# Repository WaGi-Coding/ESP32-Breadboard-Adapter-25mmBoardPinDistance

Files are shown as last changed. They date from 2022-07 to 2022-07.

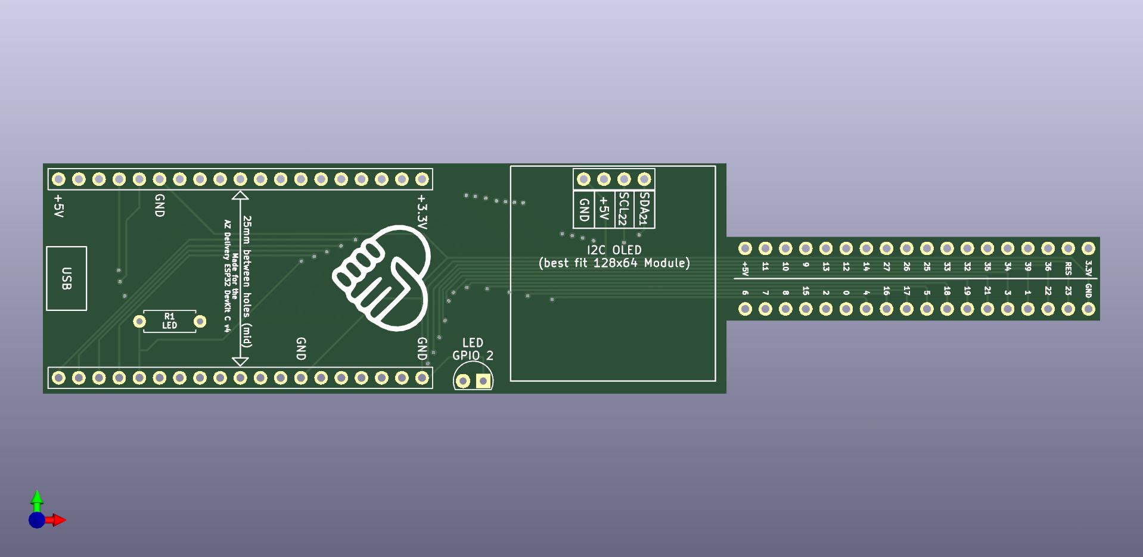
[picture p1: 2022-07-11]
ESP32_DevKit_C_v4-AZDelivery_Breadboard_Adapter.jpg

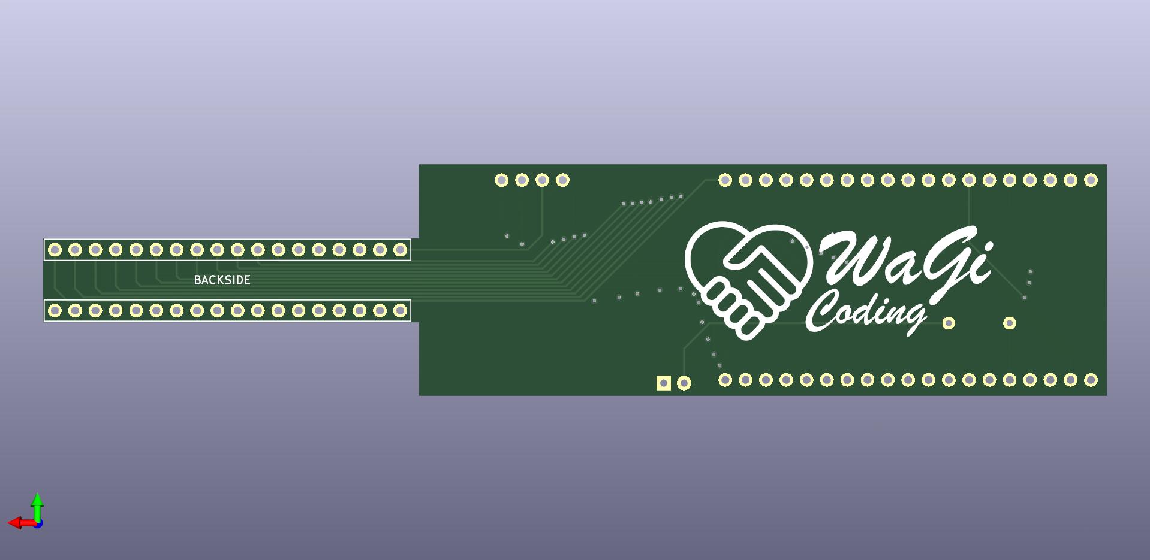
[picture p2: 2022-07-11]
ESP32_DevKit_C_v4-AZDelivery_Breadboard_AdapterBACK.jpg

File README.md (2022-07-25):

# ESP32-Breadboard-Adapter 25mm Board Pin Distance

Breadboard Adapter PCB to better fit an ESP32 DevKit onto your Breadboard. Has a Slot for a LED on GPIO2 and an OLED Screen (128x64).
The Pin Sequence is the same as from the ESP itself, just 2 Ground Pins got removed to save space.

It's designed for the "AZ-Delivery ESP32 DevKit C v4". If you have another Board, check the Pin mid distance, it should be 25mm, also check the Pinout of the mentioned Board.






You can DIRECTLY [ORDER FROM AISLER.NET HERE](https://aisler.net/p/QFYZRXHC) for very cheap. Here is also a 10€ Coupon Code (works atm [Jul. 10th 2022]): uCnet
You can also upload the files to some other PCB Manufacturer for sure.

### You need:
 - 2x 18Pin Male Header
 - 2x 19Pin Female Header (Hard to find, i cut 40 Pin Headers because they are cheap and easy to get)
 - (optional) I2C OLED Module (128x64 or something fitting ^^) [GND, 5V, SCL, SDA]
 - (optional) A LED (5mm or smaller diameter) + Resistor Connected to GPIO2

Made with KiCad

PS: It's a 1.6mm thick, 4 Layer PCB with throughhole Vias

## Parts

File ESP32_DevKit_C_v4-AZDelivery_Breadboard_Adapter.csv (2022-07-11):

ID | Bezeichner | Gehäuse | Stückzahl | Bezeichnung | Anbieter und Referenz
1 | D1 | LED_D5.0mm | 1 | LED
2 | J5 | PinHeader_1x04_P2.54mm_Vertical | 1 | Conn_01x04_Female
3 | R1 | R_Axial_DIN0207_L6.3mm_D2.5mm_P7.62mm_Horizontal | 1 | R
4 | J1,J2 | PinHeader_1x19_P2.54mm_Vertical | 2 | Conn_01x19_Female
5 | J4,J3 | PinHeader_1x18_P2.54mm_Vertical | 2 | Conn_01x18_Male

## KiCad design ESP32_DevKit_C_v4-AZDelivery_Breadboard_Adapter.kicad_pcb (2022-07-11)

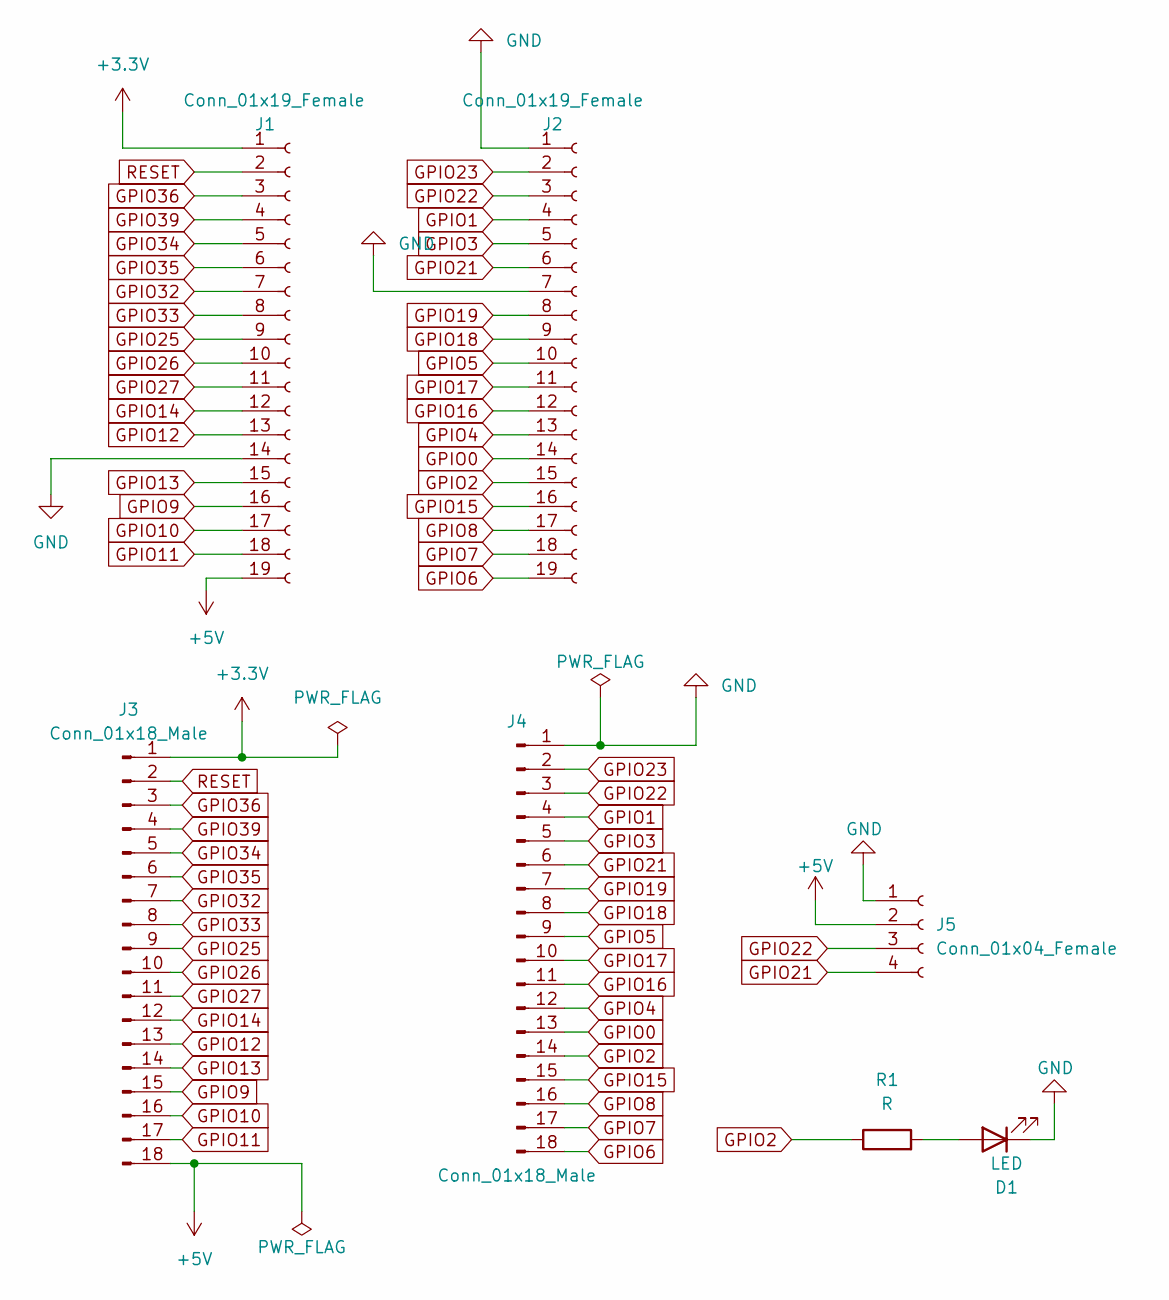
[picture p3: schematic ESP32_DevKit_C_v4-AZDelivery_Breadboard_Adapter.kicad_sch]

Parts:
D1: LED; LED_D5.0mm
J1, J2: Conn_01x19_Female; PinHeader_1x19_P2.54mm_Vertical
J3, J4: Conn_01x18_Male; PinHeader_1x18_P2.54mm_Vertical
J5: Conn_01x04_Female; PinHeader_1x04_P2.54mm_Vertical
R1: R; R_Axial_DIN0207_L6.3mm_D2.5mm_P7.62mm_Horizontal

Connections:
+3.3V: J1.1, J3.1
+5V: J1.19, J3.18, J5.2
GND: D1.1 (K), J1.14, J2.1, J2.7, J4.1, J5.1
GPIO0: J2.14, J4.13
GPIO1: J2.4, J4.4
GPIO2: J2.15, J4.14, R1.1
GPIO3: J2.5, J4.5
GPIO4: J2.13, J4.12
GPIO5: J2.10, J4.9
GPIO6: J2.19, J4.18
GPIO7: J2.18, J4.17
GPIO8: J2.17, J4.16
GPIO9: J1.16, J3.15
GPIO10: J1.17, J3.16
GPIO11: J1.18, J3.17
GPIO12: J1.13, J3.13
GPIO13: J1.15, J3.14
GPIO14: J1.12, J3.12
GPIO15: J2.16, J4.15
GPIO16: J2.12, J4.11
GPIO17: J2.11, J4.10
GPIO18: J2.9, J4.8
GPIO19: J2.8, J4.7
GPIO21: J2.6, J4.6, J5.4
GPIO22: J2.3, J4.3, J5.3
GPIO23: J2.2, J4.2
GPIO25: J1.9, J3.9
GPIO26: J1.10, J3.10
GPIO27: J1.11, J3.11
GPIO32: J1.7, J3.7
GPIO33: J1.8, J3.8
GPIO34: J1.5, J3.5
GPIO35: J1.6, J3.6
GPIO36: J1.3, J3.3
GPIO39: J1.4, J3.4
unnamed: D1.2 (A), R1.2
RESET: J1.2, J3.2

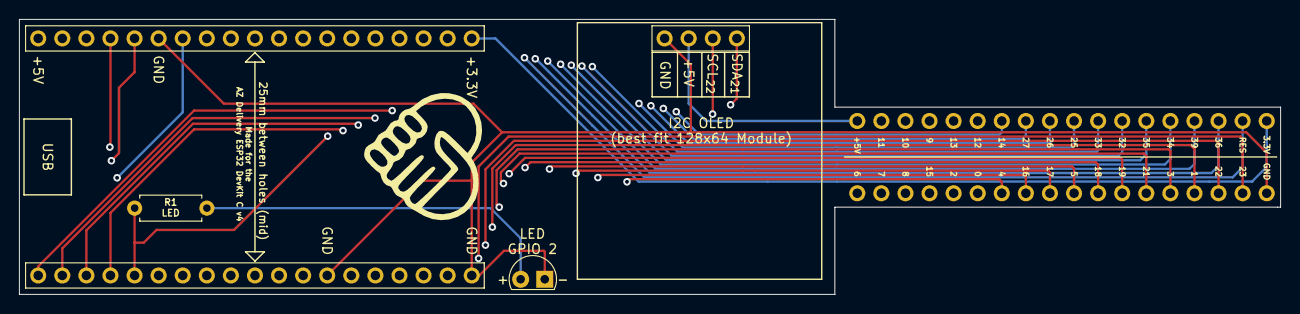
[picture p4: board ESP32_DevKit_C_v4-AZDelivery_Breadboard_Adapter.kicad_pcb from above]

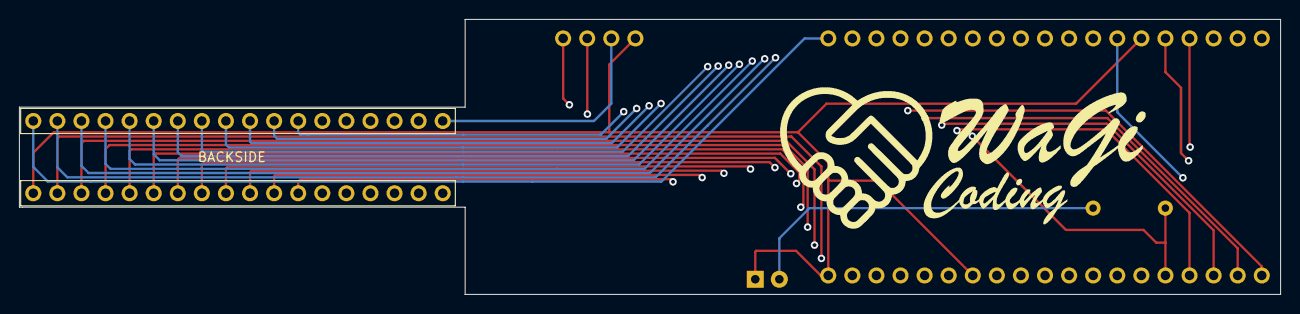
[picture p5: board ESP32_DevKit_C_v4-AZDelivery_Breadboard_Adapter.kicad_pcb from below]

Board: 4 copper layers, 133.0 x 29.0 mm, 7 parts (2 on the bottom side), 37 nets.
